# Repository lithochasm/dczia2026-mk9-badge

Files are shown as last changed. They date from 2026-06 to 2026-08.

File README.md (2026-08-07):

```
___  ____     _____  ______           _            
|  \/  | |   |  _  | | ___ \         | |           
| .  . | | __| |_| | | |_/ / __ _  __| | __ _  ___ 
| |\/| | |/ /\____ | | ___ \/ _` |/ _` |/ _` |/ _ \
| |  | |   < .___/ / | |_/ / (_| | (_| | (_| |  __/
\_|  |_/_|\_\\____/  \____/ \__,_|\__,_|\__, |\___|
                                         __/ |     
                                        |___/      
-------------------------------------------------
D C Z I A  ----------  2 0 2 6
```

DCZia Presents: The MK9 Badge

It blinks. It types. You can wear it around your neck and then set it on your desk and actually use it\*.

\* _Desk productivity not guaranteed. DCZia assumes no responsibility for keys accidentally sent during badge parties. Consult your keyboard layer documentation before operating heavy machinery._

---

## About

The **MK9** is a fully functional **3×3 mechanical macropad badge**. Nine real mechanical switches, per-key RGB lighting, ambient underglow, an accelerometer that actually does something interesting, SAO support, and MicroPython firmware — all in a package sized to hang around your neck at DEF CON and survive the week.

---

## Specs

**Keys**
- 9× mechanical switches in a 3×3 grid — standard MX footprint, swap keycaps as you please
- Ships with translucent blue keycaps
- USB HID numpad when plugged into a computer

**Lighting**
- 9× WS2812B per-key RGB LEDs — one under each switch
- 6× SK6812 side-firing LEDs — edge-mounted for ambient underglow out the sides

**Brains & Sensors**
- RP2040 microcontroller
- Accelerometer — light stays pooled at physical down as a hanging badge rotates
- 2× SAO connectors (standard 6-pin, I2C + 2 GPIO each) — expand with the badge add-on ecosystem

**Power & I/O**
- USB-C — power and data
- 3× AAA battery pack — run it untethered
- Power switch for battery mode
- Reset button + BOOTSEL button for easy firmware flashing

**Firmware**
- Native MicroPython firmware with bundled USB HID support
- QMK-compatible hardware — reflash and run it as a full QMK macropad

---

## What It Does Out of the Box

On boot: a smoothly fading rainbow flows across all keys and backlights, then
cross-fades into the active theme.

Once running:
- Nine spatial color themes animate all 15 LEDs — one theme for each key
- Pressing a key makes a white-hot impact and a colour ripple that expands across the whole board
- Long-press a key to select its theme; rotation keeps its light pooled at physical down
- Plug into a computer and it shows up as a numpad (7–9 / 4–6 / 1–3 layout)

---

## Repository

```
mk9-badge/
├── buildguide.md — badge assembly, flashing, and troubleshooting
├── hardware/   — KiCad design files, BOM, fabrication outputs
└── software/   — MicroPython firmware
```

- [Build Guide →](buildguide.md) — assembly, battery installation, flashing, and troubleshooting
- [Hardware →](hardware/README.md) — schematics, PCB layout, drill files, BOM
- [Software →](software/README.md) — firmware architecture, pinout, library requirements, flashing instructions

**Fabrication outputs**:
- [PCB layer plot](hardware/output/mk9-badge.pdf)
- [PTH drill map](hardware/output/mk9-badge-PTH-drl_map.pdf)
- [NPTH drill map](hardware/output/mk9-badge-NPTH-drl_map.pdf)

---

## Programming / Updating

The badge runs [MicroPython](https://micropython.org). To install or update it:

1. Hold **BOOTSEL** while plugging the badge into your computer — it mounts as `RPI-RP2`.
2. Drag [`firmware/RPI_PICO-20260406-v1.28.0.uf2`](firmware/RPI_PICO-20260406-v1.28.0.uf2)
   onto the drive.
3. Use Thonny or `mpremote` to upload the `software/*.py` files to `/` and
   `software/lib/` to `/lib/` on the badge.

Full commands and the recommended firmware version are in the
[software flashing guide](software/README.md#install-on-the-badge).

Want to run QMK instead? The hardware is fully compatible; QMK setup instructions will be posted separately.

**Recommended tool:** [Thonny](https://thonny.org), which can edit and upload
files directly through the MicroPython serial connection.

---

## Open Source

DCZia is committed to open source hardware and software. All design files and firmware are publicly available.

- **Live CAD (OnShape):** [View the design](https://cad.onshape.com/documents/36884624fbe35c16a5af61a7/w/233227193d278274727a44c3/e/ea987b4b53c4648fa3dc84b6)

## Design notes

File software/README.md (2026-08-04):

# MK9 Badge — MicroPython Firmware

Native MicroPython firmware for the RP2040-based DCZia MK9 badge. It has no
runtime dependency on CircuitPython or Adafruit libraries.

## Behavior

Startup is a 3.2-second smoothly fading, moving rainbow that cross-fades into
the active theme. Normal key taps still send the USB numpad layout:

```text
7 8 9
4 5 6
1 2 3
```

Hold a key for 750 ms to select its theme. A long press changes lighting and
does not send a number:

| Key | Theme |
|---:|---|
| 1 | Party Mode |
| 2 | Vaporwave |
| 3 | Deep Ocean |
| 4 | Ember |
| 5 | Matrix |
| 6 | Ultraviolet |
| 7 | Sunset |
| 8 | Glacier |
| 9 | Moonlight |

**Party Mode** (key 1) is a random-looking flicker across all 15 LEDs,
pulsing at 175 BPM by default: each beat snaps to a new random pattern,
holds it for the first 55% of the beat, then blacks out for the rest before
the next beat's pattern snaps in. The tempo is adjustable live with the
`bpm` command (see below), or
directly from the badge: while Party Mode is active, key 7 nudges it down
and key 8 nudges it up, 2 BPM per short press, and key 9 is a tap-tempo
input — tap it in time with music and the average interval between taps
becomes the new BPM (a gap longer than 2 seconds since the last tap starts a
fresh tapping sequence instead of averaging with stale ones). While Party
Mode is active, physical key presses otherwise stop sending USB numpad
keystrokes (long-press theme selection still works on every key, including
7, 8, and 9, so you can always long-press back out into a different theme).

There's also a 10th theme, **Prism** — the original default rainbow — which
isn't bound to a key (there are only 9 for 10 themes), so reach it from the
serial console with `theme 10` or `theme prism`.

Every press creates a spatial ripple. As a hanging badge rotates, the current
theme's light quickly follows physical down and gathers like liquid at the
lowest edge or corner, with a short overshoot and settling shoreline wobble.
Forward/back tilt and quick movement do not change the pool while it is
hanging; Z smoothly suppresses the effect when the badge is laid flat. If the
accelerometer is not responding, the keys, LEDs, and USB keyboard continue to
work.

## Hardware map

| Function | GPIO |
|---|---|
| 15-pixel WS2812/SK6812 chain | GP21 |
| Matrix rows R0/R1/R2 | GP27, GP26, GP16 |
| Matrix columns C0/C1/C2 | GP17, GP13, GP0 |
| MSA301/GSDA213 SDA/SCL | GP18, GP19 (I2C1) |
| SAO SDA/SCL | GP9, GP10 (software I2C) |
| SAO GPIO | GP29, GP28, GP12, GP11 |

The key scanner drives one column high and reads rows with pull-downs. This
matches the PCB's column → switch → diode → row orientation.

### Physical layout

Traced from the PCB netlist (switch → diode → row nets, and each LED's
DIN/DOUT chain position), viewed from the front of the badge:

```text
                 ┌──[pwr]──[ USB-C ]──[boot]──[reset]──┐
                 │                                     │
     D27 ●       │    [ 7 ]      [ 8 ]      [ 9 ]      │       ● D22
  (pixel 14)     │   key 0       key 1       key 2     │    (pixel 9)
                 │   pixel 0     pixel 1     pixel 2   │
                 │                                     │
                 │    [ 4 ]      [ 5 ]      [ 6 ]      │
                 │   key 3       key 4       key 5     │
     D26 ●       │   pixel 3     pixel 4     pixel 5   │       ● D23
  (pixel 13)     │                                     │    (pixel 10)
                 │    [ 1 ]      [ 2 ]      [ 3 ]      │
                 │   key 6       key 7       key 8     │
                 │   pixel 6     pixel 7     pixel 8   │
                 │                                     │
                 └──────────●───────────●──────────────┘
                           D25          D24
                        (pixel 12)   (pixel 11)
```

| Key index | Pixel index | Numpad digit | Row/Col nets | Switch ref | LED ref | Physical position |
|---|---|---|---|---|---|---|
| 0 | 0 | 7 | R0,C0 | SW4 | D13 | top-left |
| 1 | 1 | 8 | R0,C1 | SW5 | D14 | top-middle |
| 2 | 2 | 9 | R0,C2 | SW6 | D15 | top-right |
| 3 | 3 | 4 | R1,C0 | SW7 | D16 | mid-left |
| 4 | 4 | 5 | R1,C1 | SW8 | D17 | mid-middle |
| 5 | 5 | 6 | R1,C2 | SW9 | D18 | mid-right |
| 6 | 6 | 1 | R2,C0 | SW10 | D19 | bottom-left |
| 7 | 7 | 2 | R2,C1 | SW11 | D20 | bottom-middle |
| 8 | 8 | 3 | R2,C2 | SW12 | D21 | bottom-right |

Key index and pixel index match for all 9 keys — the per-key LEDs are simply
the first 9 pixels in the chain, so `badge.py` indexes straight into
`frame[key]` with no translation. Pixels 9-14 are the 6 side-firing
underglow LEDs (2 per left/right edge, 2 along the bottom); the top edge has
none since it's occupied by USB-C, the power switch, and the reset/BOOTSEL
buttons.

## Firmware structure

```text
software/
├── boot.py          USB serial + HID setup
├── main.py          MicroPython entry point
├── badge.py         keys, long presses, motion, ripples, main loop
├── themes.py        startup rainbow and all nine themes
├── hardware.py      NeoPixels, matrix, accelerometer, and SAO setup
├── key_matrix.py    active-high scanner with software debounce
├── msa301.py        native accelerometer driver
├── color_tools.py   portable RGB math
├── config.py        pins and user-tunable timing/brightness
├── usb_keyboard.py  non-blocking numpad reports
├── serial_menu.py   typed USB-serial console (help/status/theme/brightness/accel/reset/bootloader)
├── rooms.py         text-adventure room data — this is where you write your game
├── game.py          text-adventure state machine (movement, inventory, save/load)
├── user_config.py   persisted theme/brightness/party-bpm settings, loaded on boot
└── lib/usb/         official MicroPython USB device libraries
```

## Serial console

While the badge is running (not just at the REPL), the USB-CDC serial
connection also accepts typed commands — connect with `mpremote connect auto
repl`, Thonny's shell, or any serial terminal, then type `help` and press
Enter for the full command listing (`status`, `theme [n|name]`, `brightness
[0-100]`, `bpm [1-999]`, `accel`, `reset`, `bootloader`). Typing anything at
all before you've seen the listing prints it automatically. Ctrl-C still
drops to the real MicroPython REPL and kills the running badge script, same
as always — that's unrelated to and unaffected by the console.

Changing the theme (long-press or `theme`), `brightness`, or `bpm` (Party
Mode's tempo) saves all three settings to `/user_config.json` on the badge's
flash filesystem, and they're restored automatically the next time the badge
boots.

## Text adventure

Typing `play` at the serial console starts a small text-adventure game that
runs inside the same firmware, taking over the typed console until you type
`quit`. All game content — room names/descriptions, exits, and puzzles —
lives in `rooms.py`; fill that in with your own 9 rooms. `game.py`'s
plumbing (movement, inventory, save/load, room-status LEDs) needs no changes
to add content.

While the game is active the 9 physical keys stop sending USB numpad
keystrokes and stop selecting lighting themes. Instead, each key becomes a
purely visual status board for the room of the same index (key 1 = room 0,
etc.) — pressing a key does not move you:

| Color  | Meaning |
|---|---|
| Red | Room not yet visited |
| Yellow | Visited, puzzle not yet solved  |
| Green  | Visited, puzzle solved |

Commands: `look`, `go <direction>` (per-room exits, not fixed compass
directions), `take` (picks up the current room's item, if any), `use <item>`
(only works on items you're carrying), `hint`, `inventory` (`inv`/`i`),
`save`, `load`, `restart` (wipes progress and starts over), `help`, `quit`.
Progress saves to `/game_save.json` on the badge's flash filesystem
automatically when you `quit`, or on demand with `save`.

## Install on the badge

1. Hold **BOOTSEL** while plugging in the badge. It appears as `RPI-RP2`.
2. Copy the included `firmware/RPI_PICO-20260406-v1.28.0.uf2` onto `RPI-RP2`.
   It is the official stable v1.28 build from
   [micropython.org/download/RPI_PICO](https://micropython.org/download/RPI_PICO/).
3. The badge reboots into MicroPython. Unlike CircuitPython, it does not expose
   a drag-and-drop source drive. Use Thonny or `mpremote` to upload the files.

In Thonny, select **MicroPython (Raspberry Pi Pico)**, then upload every `.py`
file in `software/` to `/` and upload `software/lib/` as `/lib/`.

With `mpremote`:

```sh
cd software
mpremote connect auto fs mkdir :lib
mpremote connect auto fs mkdir :lib/usb
mpremote connect auto fs mkdir :lib/usb/device
mpremote connect auto fs cp *.py :
mpremote connect auto fs cp lib/usb/__init__.py :lib/usb/__init__.py
mpremote connect auto fs cp lib/usb/device/*.py :lib/usb/device/
mpremote connect auto reset
```

From the repository root, `tools/upload_micropython.sh` runs those commands
for you.

If a directory already exists, its `mkdir` command may print an error; continue
with the copy commands. `boot.py` deliberately keeps the serial REPL enabled
while adding the HID keyboard.

## Configuration

Edit `config.py` to change global brightness, long-press time, frame rate, or
pin assignments. Add or modify palettes and renderers in `themes.py`.
`GLOBAL_BRIGHTNESS` and `PARTY_BPM` are only the boot-time defaults — the
serial console's `brightness` and `bpm` commands can also change them live,
without reflashing, and those choices (along with the active theme) persist
across reboots via `user_config.py`.

## Verification

Host-side logic tests do not require a badge:

```sh
python3 -m unittest discover -s tests -v
python3 -m compileall -q software testing tests
```

For physical diagnostics, see [`testing/README.md`](../testing/README.md).

The bundled `lib/usb/` modules come from the official MIT-licensed
`micropython-lib` project; its license is retained under `third_party/`.

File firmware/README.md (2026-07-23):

# MicroPython UF2

`RPI_PICO-20260406-v1.28.0.uf2` is the official stable MicroPython v1.28.0
firmware for the Raspberry Pi Pico/RP2040 target, downloaded from:

<https://micropython.org/download/RPI_PICO/>

SHA-256:

```text
00aedb8431ebea83b470ef909509f16432c5b1b43e8f6eaf015f6f9560bc8152
```

Hold BOOTSEL while plugging in the badge, then copy the UF2 onto the `RPI-RP2`
drive. The drive will disappear when flashing finishes. Upload the Python files
afterward using Thonny or `tools/upload_micropython.sh`.

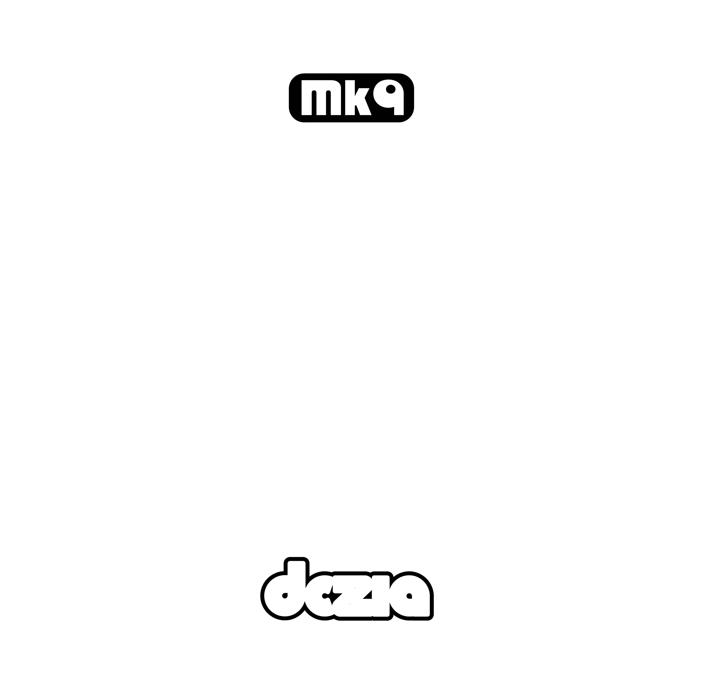
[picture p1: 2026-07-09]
hardware/images/Board_Silk.png

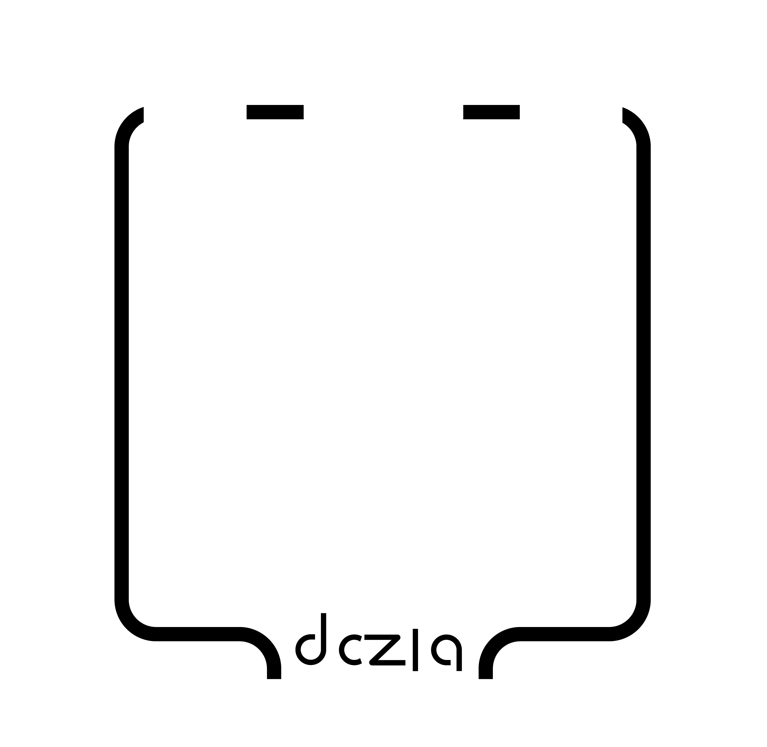
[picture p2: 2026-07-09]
hardware/images/Board_Copper.png

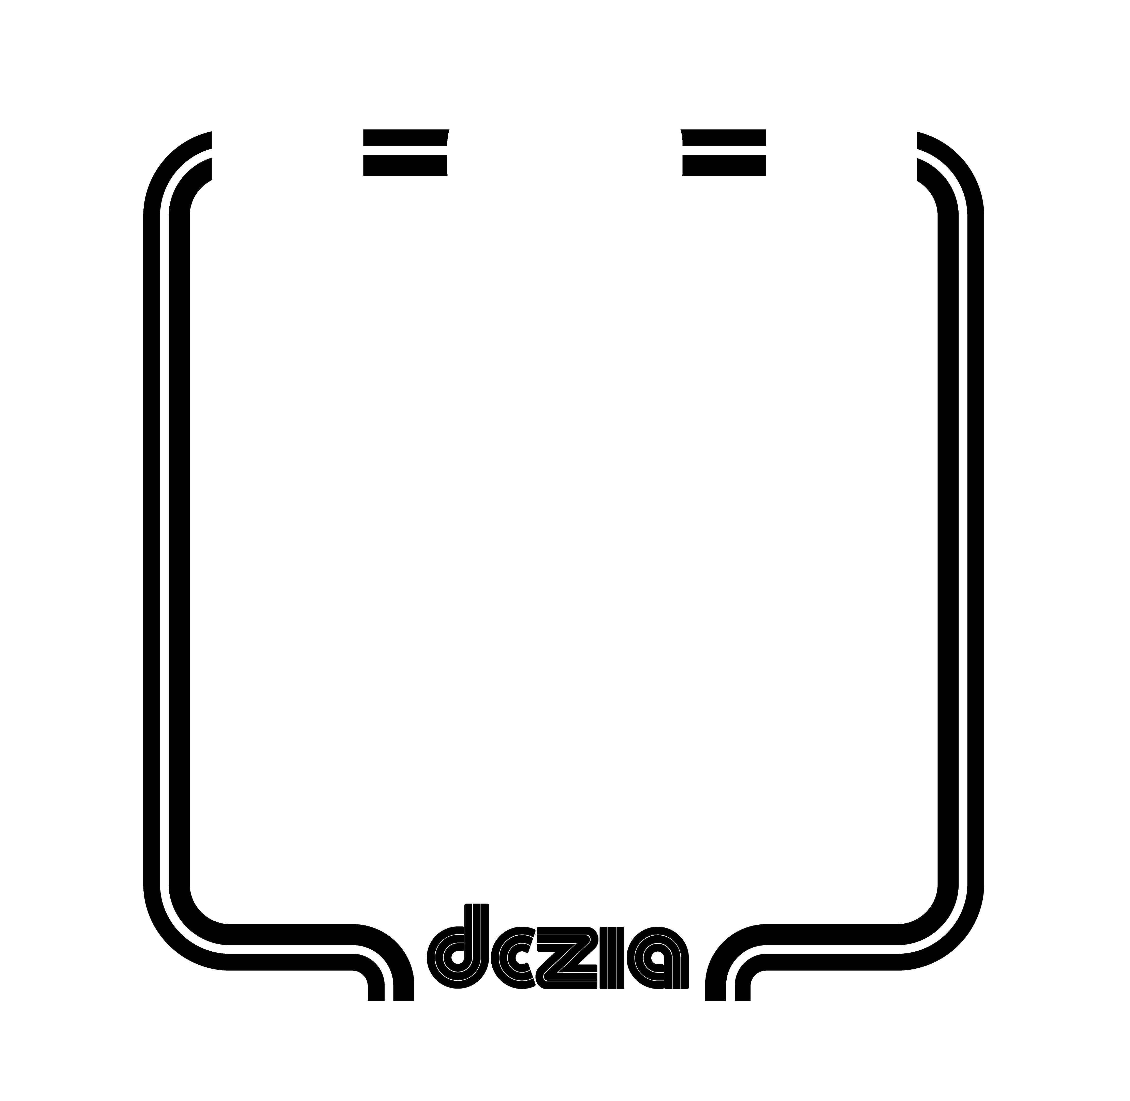
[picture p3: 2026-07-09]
hardware/images/Board_Mask.png

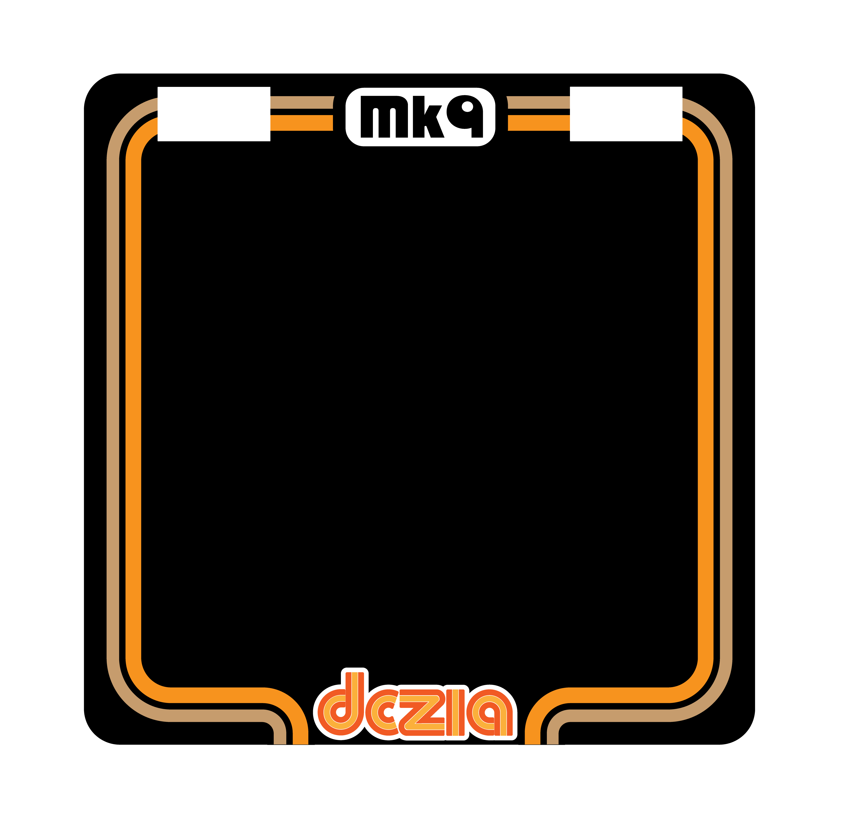
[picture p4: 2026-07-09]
hardware/images/Board_Art.png

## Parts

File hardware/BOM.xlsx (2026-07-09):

Reference | Feeder | Value | Footprint | Part Number | Distributor | Distributor Part | Datasheet | Qty | Cost Each | Qty Ordered | QOH | Notes
C3,C5,C6,C8-C12,C15-C20 |  | 0.1uF | 0603 |  |  |  | ~ | 14 | 0.004 | 0 | 2500
C4,C7,C13,C14 |  | 1uF | 0603 |  |  |  | ~ | 4 | 0.004 | 0 | 3500
C1,C2 |  | 15pF | 0603 |  |  |  | ~ | 2 | 0.004 | 0 | 3500
D2-12 |  | D_Schottky | SOD-123 |  | Digikey | 3757-SS0540_R1_00001DKR-ND | https://www.panjit.com.tw/upload/datasheet/SS0520_SERIES.pdf | 2 | 0.11 | 0 | 2500
D13-21 |  | WS2812B | LED_SMD:LED_WS2812B_PLCC4_5.0x5.0mm_P3.2mm |  | Aliexpress | https://www.aliexpress.us/item/2251832628463811.html | https://cdn-shop.adafruit.com/datasheets/WS2812B.pdf | 9 | 0.07 | 0 | 2000
D22-27 |  | SK6812 |  |  | Aliexpress |  |  | 6 | 0.1 | 1000 | 0
D1 |  | TVS |  | SP0502BAHTG | Mouser | 576-SP0502BAHTG | https://www.littelfuse.com/assetdocs/tvs-diode-array-spasp050xba-lead-free-green-datasheet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 | 0 | 0.383 |  |  | Optional stuffing
J1 |  | USB-C | Connector_USB:USB_C_Receptacle_HCTL_HC-TYPE-C-16P-01A |  | Aliexpress | https://www.aliexpress.us/item/3256805324706422.html | https://www.lcsc.com/datasheet/lcsc_datasheet_2211161000_HCTL-HC-TYPE-C-16P-01A_C2894897.pdf | 1 | 0.19 | 150 | 100
R1,R7 |  | 1k | 0603 |  |  |  | ~ | 2 | 0.001 | 0 | 4500
R6,R8 |  | 10k | 0603 |  |  |  | ~ | 2 | 0.001 | 0 | 4500
R2,R3 |  | 5.1k | 0603 |  |  |  | ~ | 2 | 0.001 | 0 | 4500
R4,R5 |  | 27R | 0603 |  |  |  | ~ | 2 | 0.001 | 0 | 4500
R9 |  | 10R | 0603 |  |  |  | ~ | 1 | 0.001 | 0 | 4500
R10,R11 |  | 4.7k | 0603 |  |  |  |  | 2 | 0.001 | 5000 | 0
S1,S3 |  | SPST Push w/boss | Button_Switch_SMD:SW_SPST_EVQP7C | EVQ-P7C01P | Digikey | P16765CT-ND | https://api.pim.na.industrial.panasonic.com/file_stream/main/fileversion/245500 | 2 | 0.20204 | 300 | 0
S2 |  | SW_SPDT | lib_fp:SW_SPDT_CK-JS102011SAQN | JS102011SAQN | Digikey | 401-1999-1-ND | https://ckswitches.com/media/1422/js.pdf | 1 | 0.6032 | 150 | 0
S4-12 |  | CherryMX Blue |  |  | Aliexpress |  |  | 9 | 0.1 | 1000 | 0
U3 |  | NCP115ASN330T2G | Package_TO_SOT_SMD:SOT-23-5 | NCP115ASN330T2G | Digikey | NCP115ASN330T2G | https://www.onsemi.com/pdf/datasheet/ncp115-d.pdf | 1 | 0.0677 | 0 | 2500
U2 |  | RP2040 | Package_DFN_QFN:QFN-56-1EP_7x7mm_P0.4mm_EP3.2x3.2mm | SC0914(7) | Mouser | 358-SC09147 | https://datasheets.raspberrypi.com/rp2040/rp2040-datasheet.pdf | 1 | 0.8 | 0 | 1000
U4 |  | W25Q128JVSIM |  |  | Digikey | W25Q128JVSIM-ND | https://www.winbond.com/resource-files/W25Q128JV%20RevI%2008232021%20Plus.pdf | 1 | 2.51556 | 133 | 0
U1 |  | GSDA213 | Kionix_LGA-12_2x2mm_P0.5mm_LayoutBorder2x4y | GSDA213 | Digikey | 4786-GSDA213TR-ND | https://goodarksemi.com/docs/datasheets/mems/GSDA213_SDS.pdf | 1 | 0.6595 | 150 | 0
X1,X2 |  | Badgelife_sao_connector_v169bis | lib_fp:Badgelife-Shitty-v1.69bis | VIRTUAL |  |  |  | 2
Y1 |  | Crystal | Crystal:Crystal_SMD_3225-4Pin_3.2x2.5mm | ABM8-272-T3 | Digikey | 535-ABM8-272-T3DKR-ND | https://abracon.com/datasheets/ABM8-272-T3.pdf | 1 | 0.4085 | 150 | 0
 |  | Key caps |  |  |  |  |  | 9 | 0.19 | 1500
` |  | Battery boxes |  |  |  |  |  | 1 |  | 125
 |  | PCB |  |  |  |  |  | 1 |  | 200
 |  | Batteries |  |  | Amazon |  |  | 3 | 0.15 | 300
 |  | Badge Run, units | 120

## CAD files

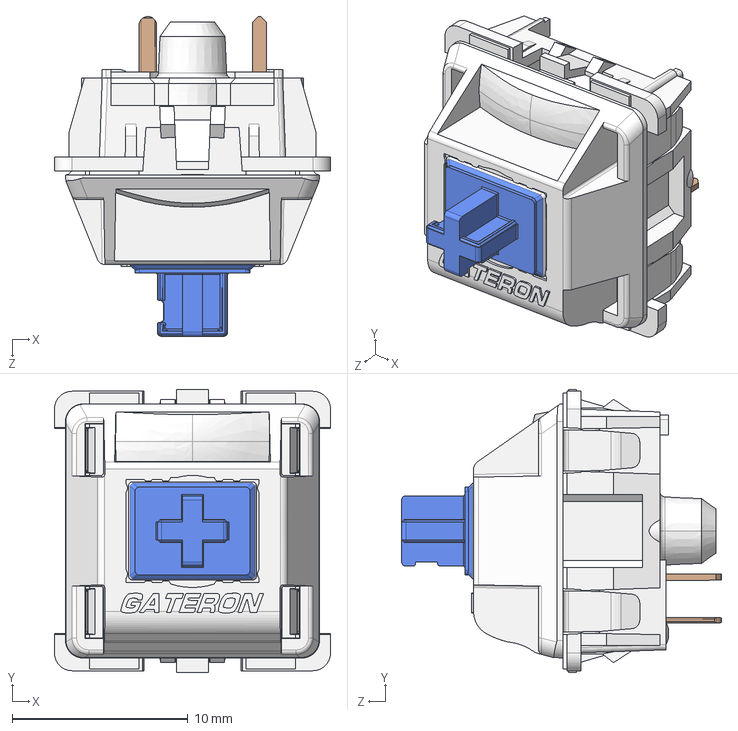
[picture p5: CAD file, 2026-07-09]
hardware/3d/G_PRO_3.0_Switch_KS-9E10B055NN-Y51_1.STEP
15.7 x 16.1 x 18.2 mm

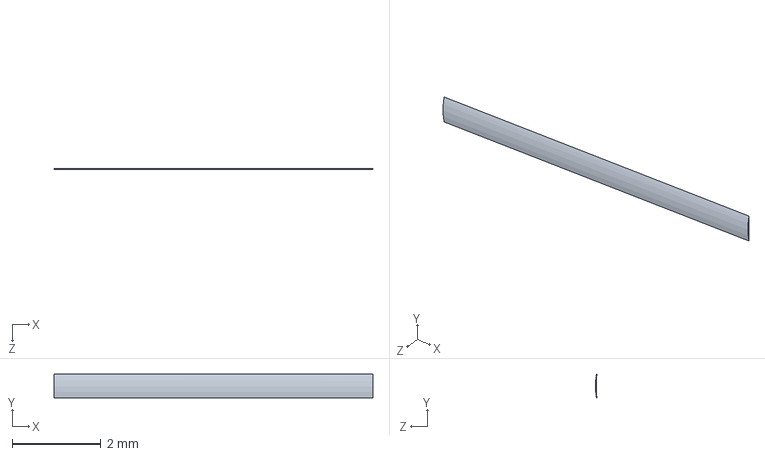
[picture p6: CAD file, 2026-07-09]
hardware/3d/G_PRO_3.0_Switch_KS-9E10B055NN-Y51_2.STEP
7.20 x 0.536 x 0.0331 mm

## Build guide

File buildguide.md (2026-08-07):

## TL;DR Instructions

1. Take the diffuser and back case off the badge using the included allen wrench
2. Solder on the keyswitches
3. Solder on the battery holder.
4. Reasseble the diffuser + case
5. Flash the badge with the u2f firmware from github / link can be found on www.dczia.net

## Intro

Thanks for purchasing the 2026 DCZia “mk9” badge! This badge is a throwback to our earlier keygrid badge from 2018. The badge features 9 mechanical MX style key switches (Gateron Blues), an accelerometer for sensing movement and adjusting the light patterns, and the badge can function as a usb keyboard / macro pad. By default the badge will output the keystrokes 1-9 like a num pad, but you can modify the code or flash QMK to use a full programmable macropad if you want. The badge is powered by an RPI 2040 microcontroller, with a 16mb flash module for expansion. An accelerometer is included as well.

## Building

The badge is shipped with the frosted diffuser, and back case pre installed. You will need to remove these pieces to safely solder on the keyswitches. Use the included allan key to disassemble the case.

[]()

Now you can install one keyswitch, and solder it onto the board. Please go slow, and try to line up the switch carefully. Sometimes some tape can be useful to keep the switch in place. Solder on all 9 key switches.

Next solder on the battery pack. The red wire will go to the “+” pad on the back of the pcb, and the black wire to the “-” pad. The badge can be fully powered over USB C if you do not wish to attach the battery pack.

After the battery pack is installed, reassemble the case, and gently screw it back together. 

Next, using the round double sticky tape, apply it to the battery pack, and then stick it to the frosted diffuser. Press gently on the battery pack for about 15 seconds to make sure you have good adhesion.

Finally install the batteries. Goto www.dczia.net, and click on the badge to be taken to the Github page for this project. Download the release which will have the source code, and a u2f file. Plug the badge into your computer and hold down the “Boot” button on the badge while plugging it in. You will need a pen or toothpick to press in the switch while plugging in the USB C cable. This will place the badge into bootloader mode. A usb drive should appear on your machine if you are using something common (Win / Mac) or if you don’t have an automounter and you are running linux, you can probably figure out how to mount the device as a drive. Drag the U2F file over to this drive. It will disconnected as soon as the transfer completes and the badge should reboot and begin showing some blinky lights!

## Badge Manual

Pressing any of the 9 keys will flash that keyswitch momentarily. Long pressing on one of the 9 keys will change the light themes. The accelerometer will allow you to tilt the badge in any of the light themes to affect the light pattern. Pressing any of the keys while plugged into usb c will output the keystroke 1-9. 

## Troubleshooting

*When i tilt my badge nothing happens?*

Some of the accelerometers may have gotten placed a bit off the pads. Find hamster for help, or if you have a hot air station, mask around the U1? part with kapton tape, and heat it gently while holding it down with some tweezers to realign to the pads. 

*Not all the keys are working?*

Re-check your solder connections on each switch

*The badge caught fire!*

The badge should only be powered by 3x AA batteries or USB-C. Please do not use car batteries, 120V AC, or small nuclear reactors to power the badge.

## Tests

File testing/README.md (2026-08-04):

# MicroPython Hardware Tester

Upload the production `software/` files first, then upload `testing/main.py`
as `/main.py` on the badge. Reset it to start the test.

- All 15 LEDs continuously sweep through red, green, and blue.
- Holding a key turns its matching LED white.
- Tilting the badge turns the matching perimeter edge white and prints live
  X/Y/Z acceleration every half second.
- If the accelerometer is missing, all six perimeter LEDs blink red.

The key numbers are row-major:

```text
1 2 3
4 5 6
7 8 9
```

Restore `software/main.py` as `/main.py` when testing is finished.

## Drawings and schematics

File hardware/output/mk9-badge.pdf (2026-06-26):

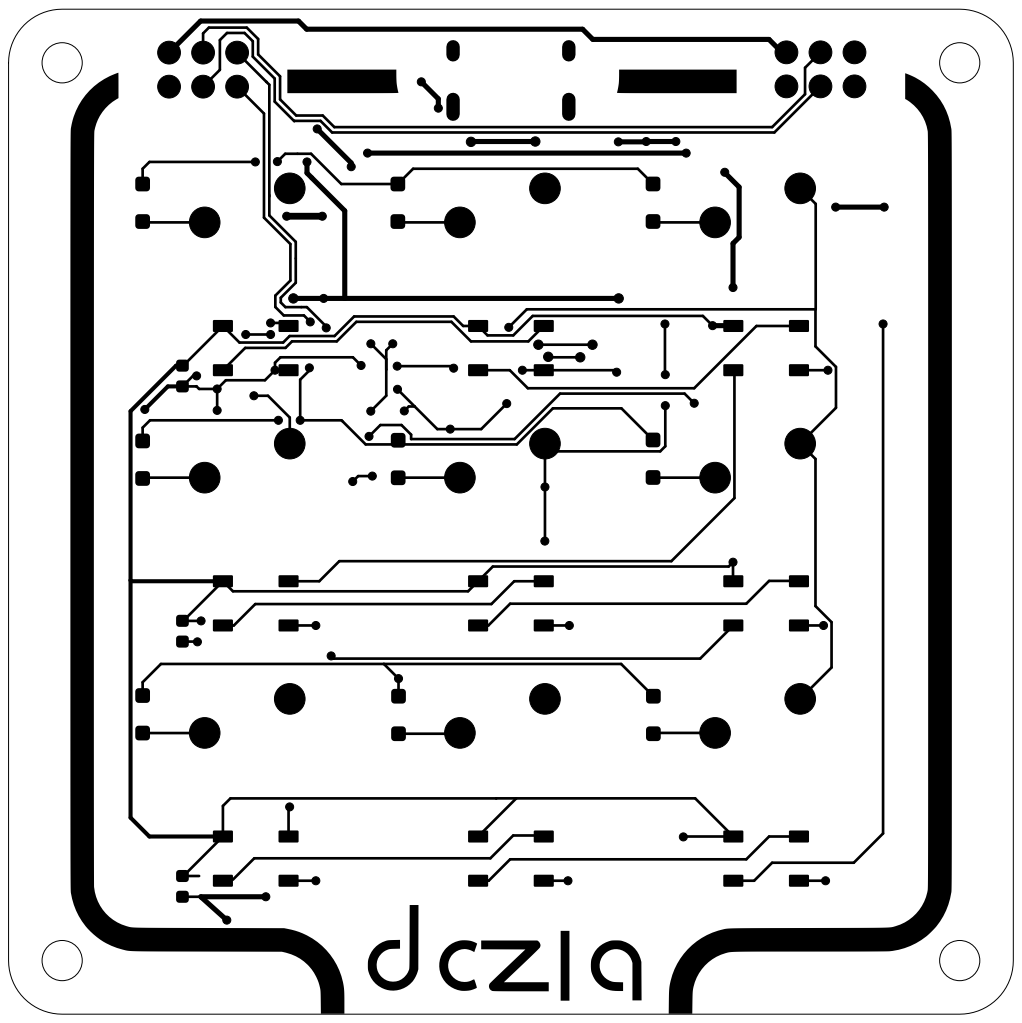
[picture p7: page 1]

Size: USLetter | Rev: 1.0
KiCad E.D.A. 10.0.4 | Id: 1/11

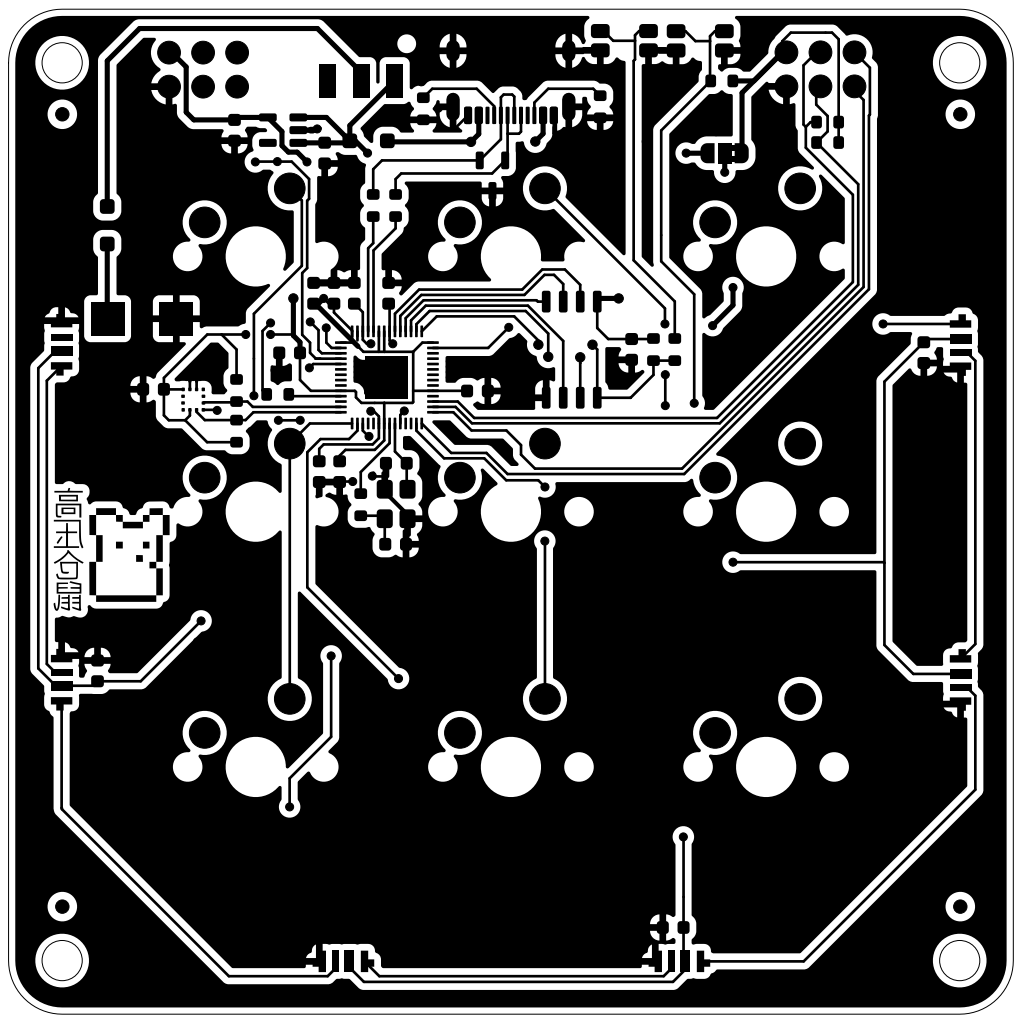
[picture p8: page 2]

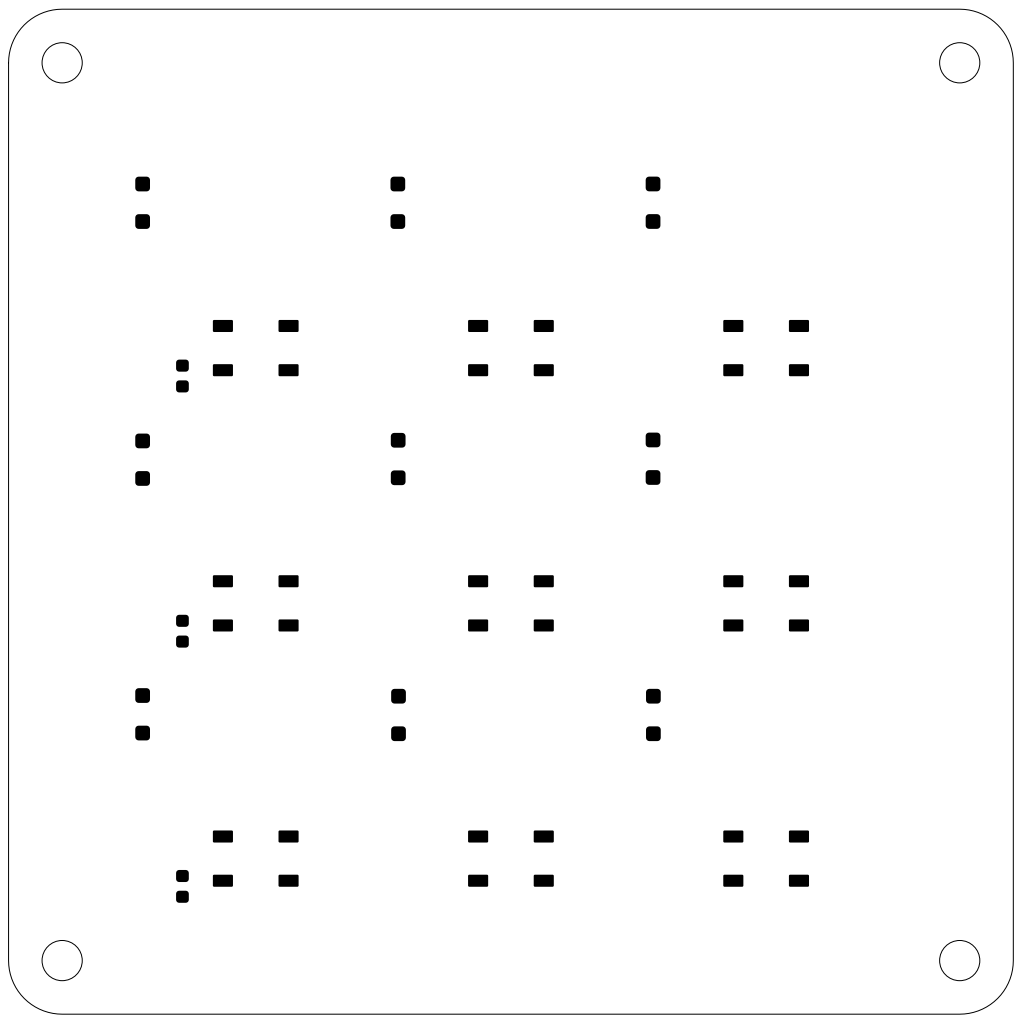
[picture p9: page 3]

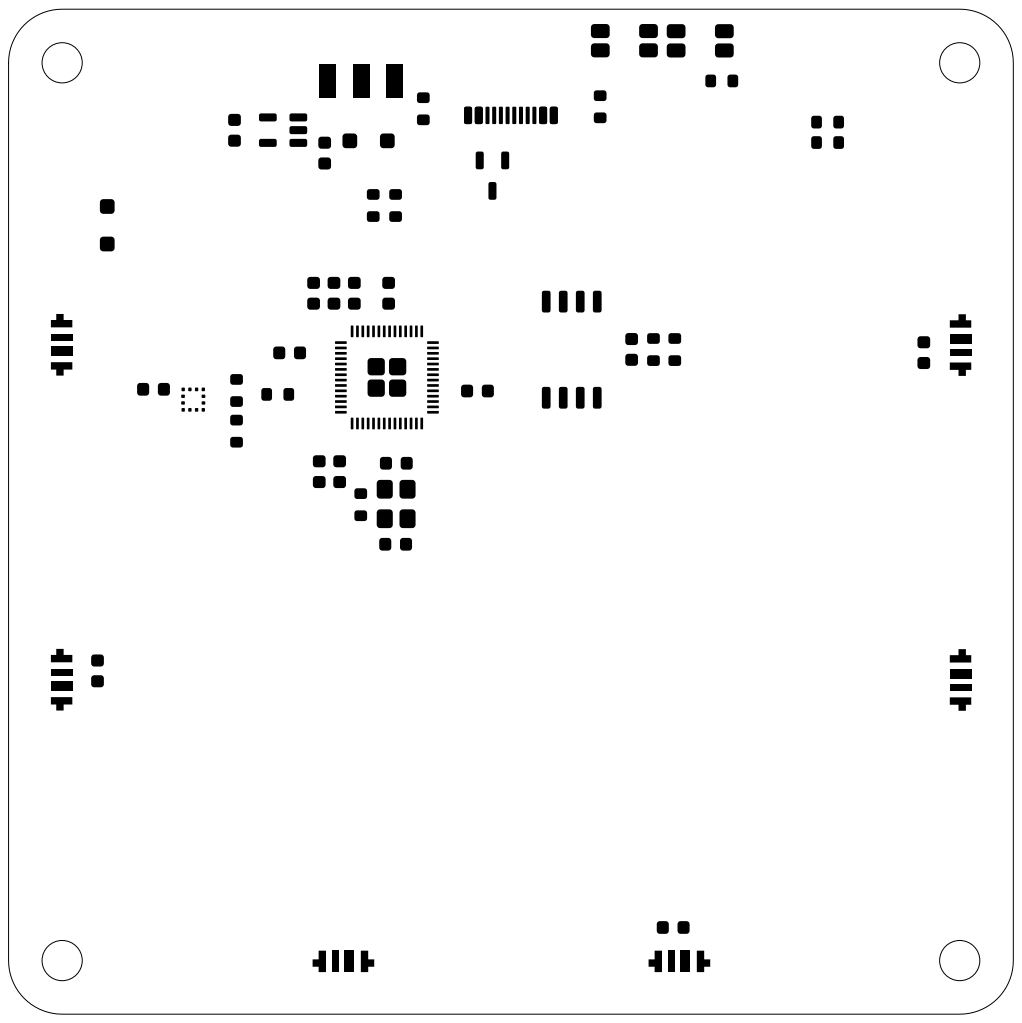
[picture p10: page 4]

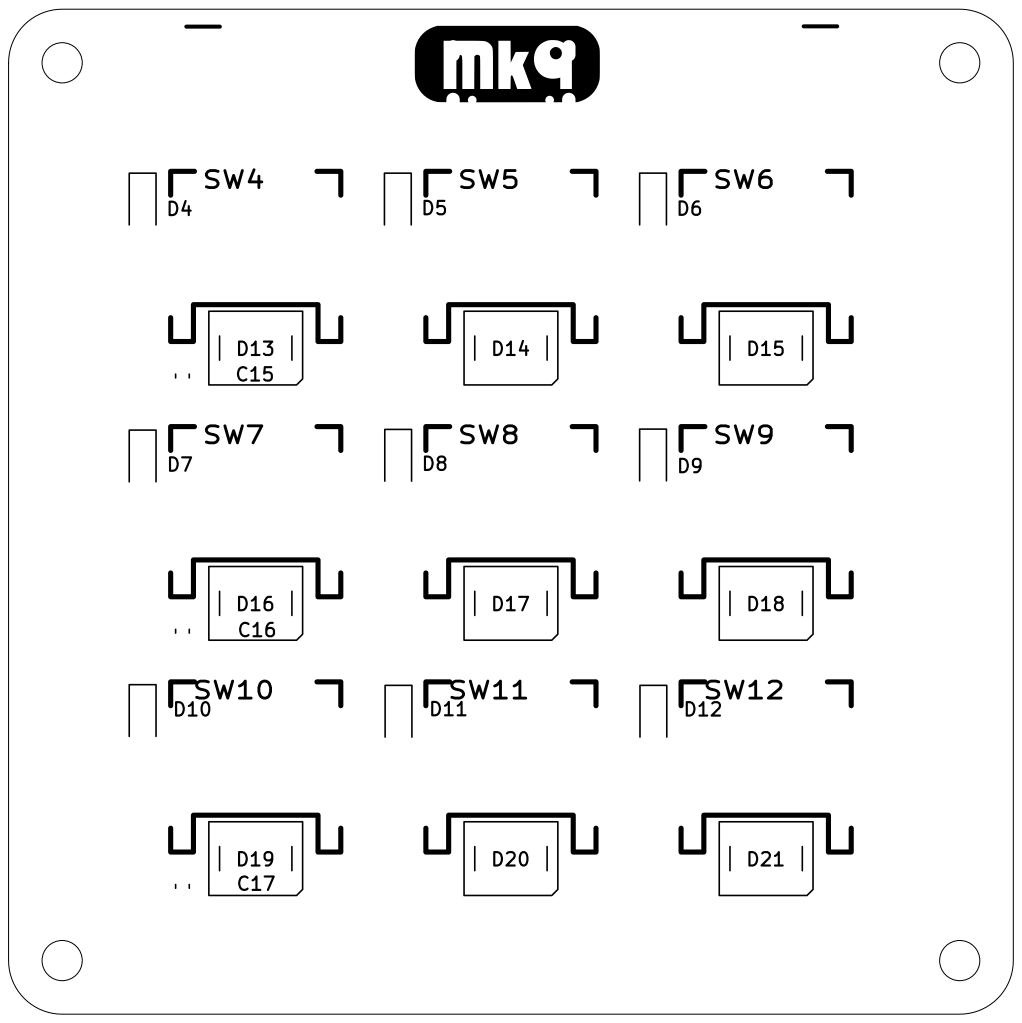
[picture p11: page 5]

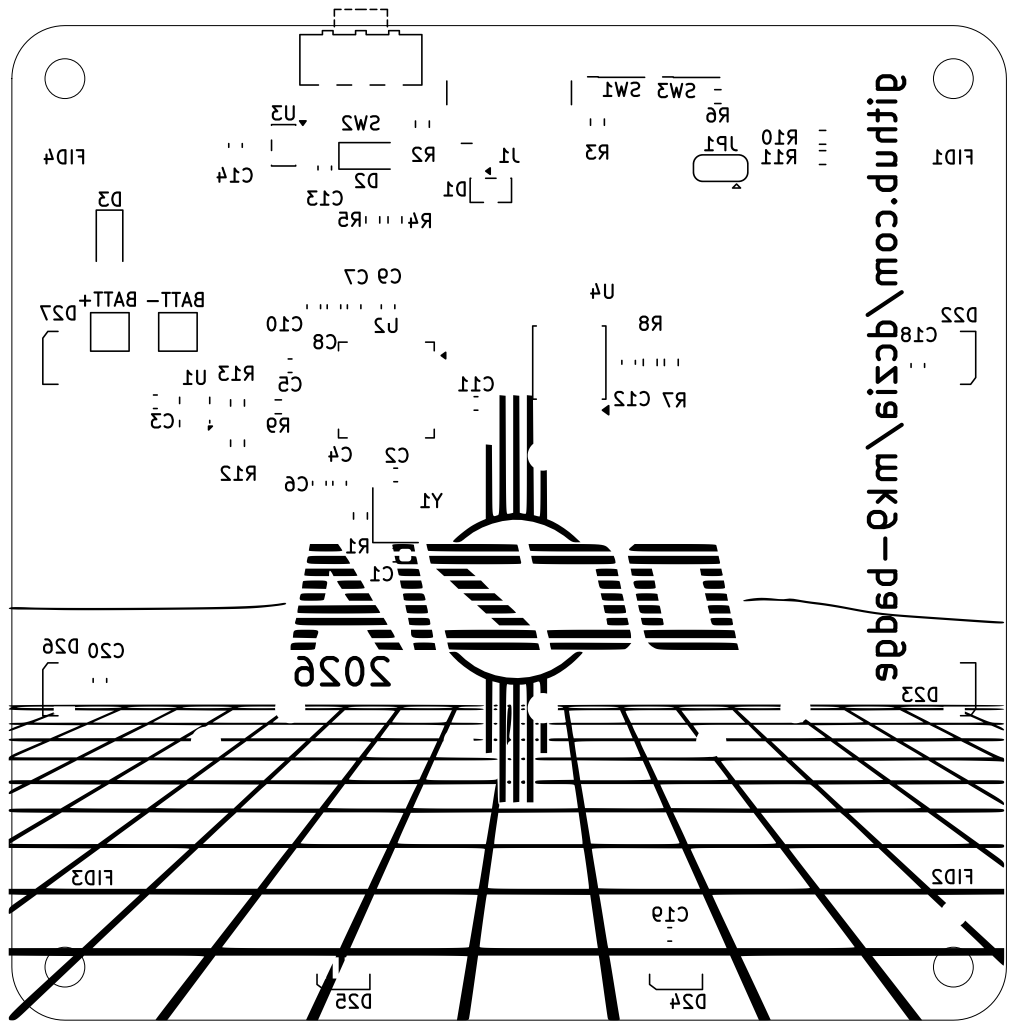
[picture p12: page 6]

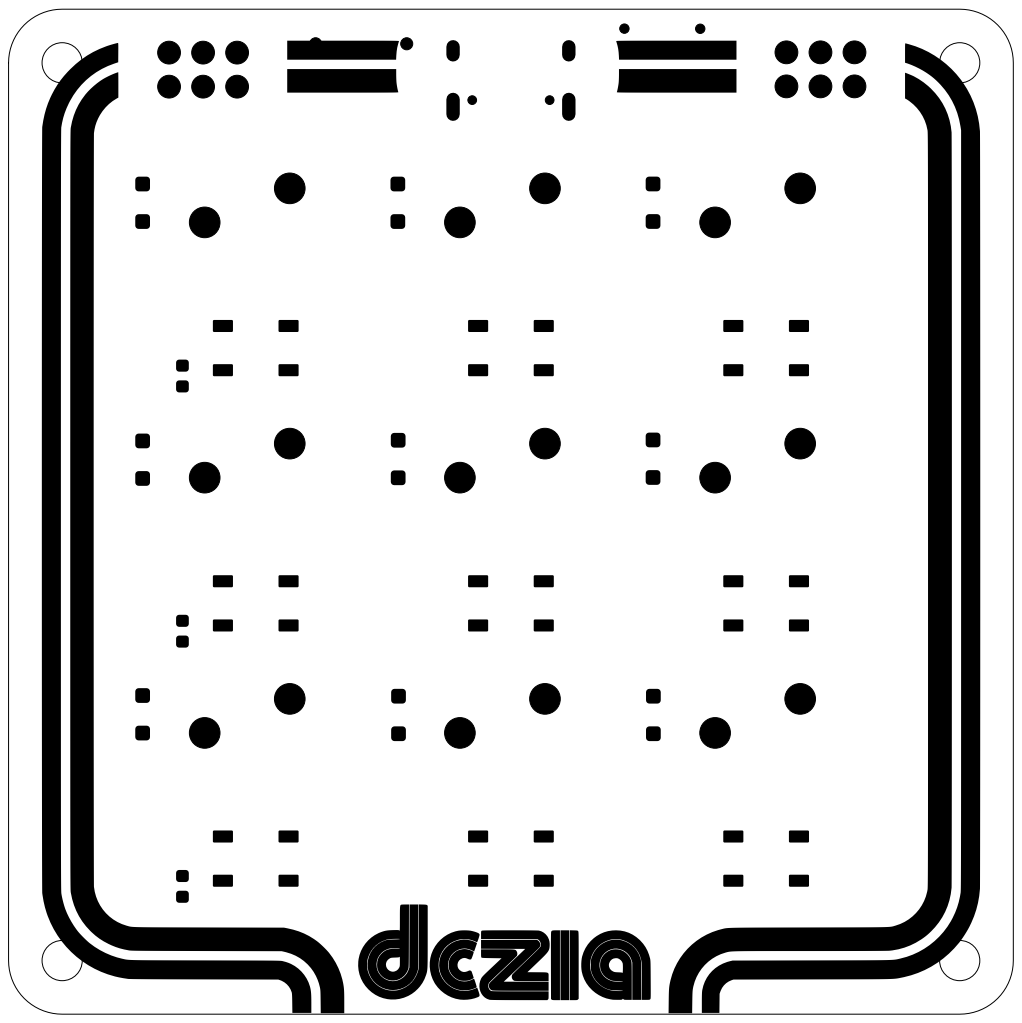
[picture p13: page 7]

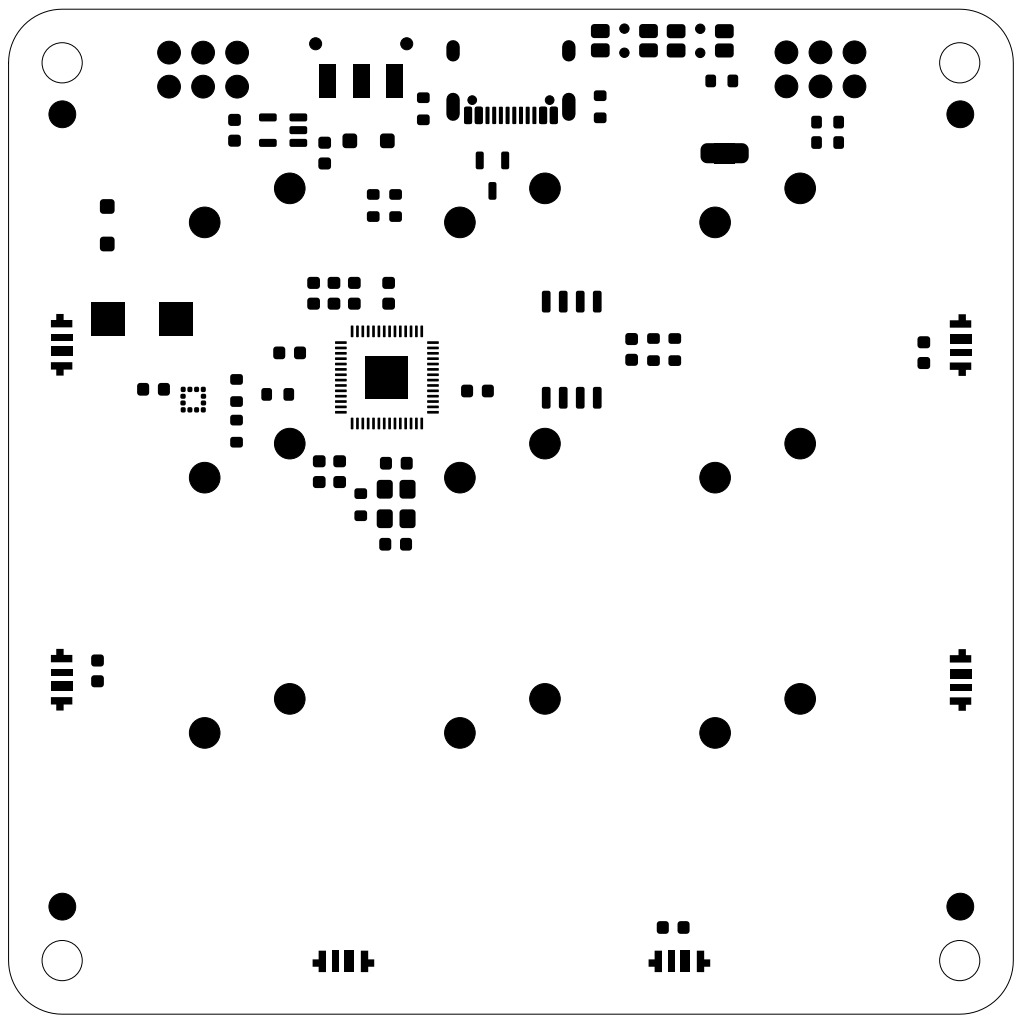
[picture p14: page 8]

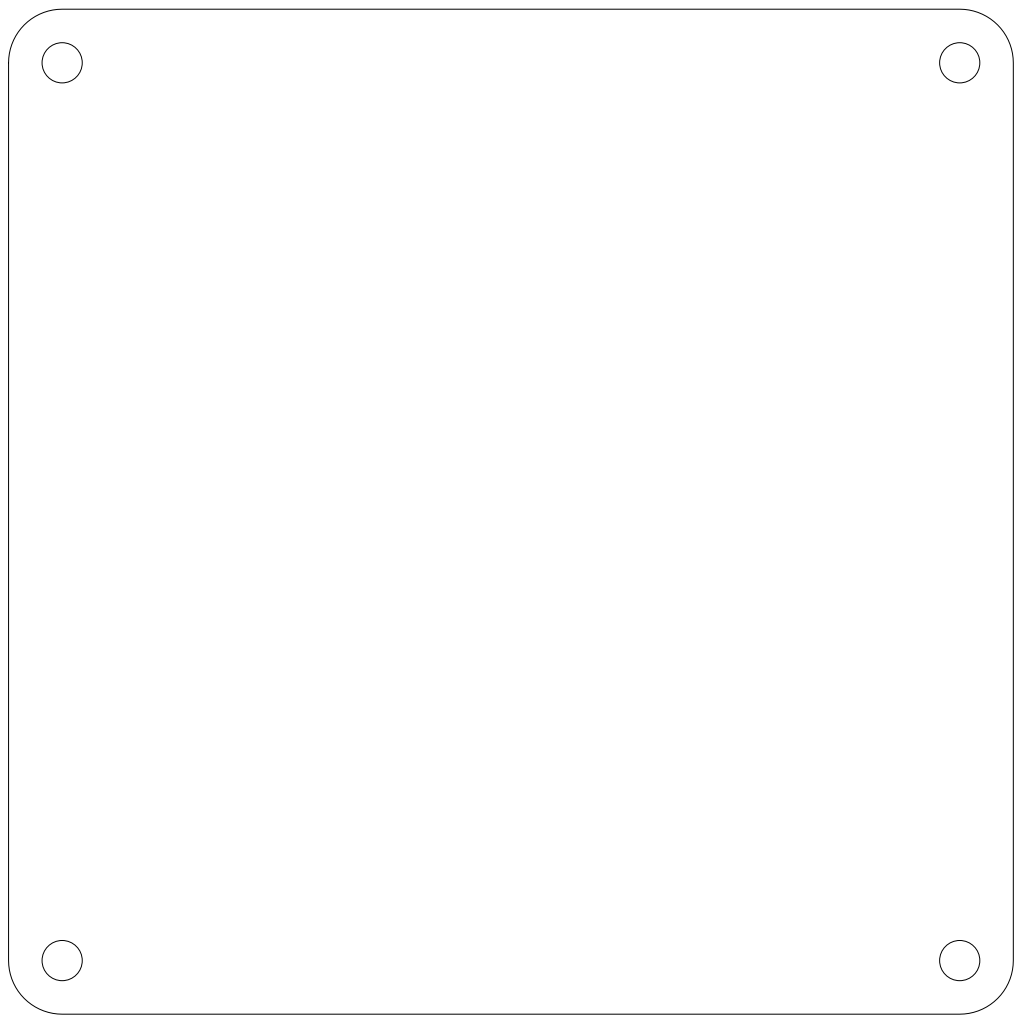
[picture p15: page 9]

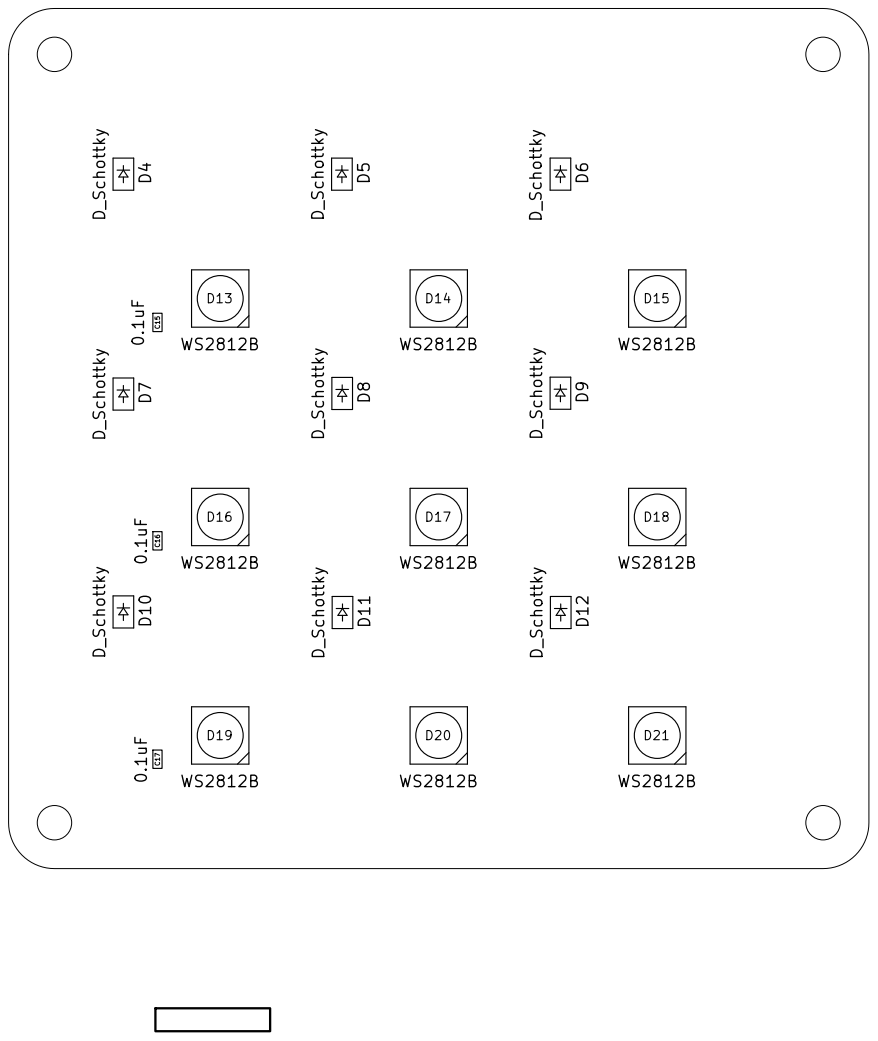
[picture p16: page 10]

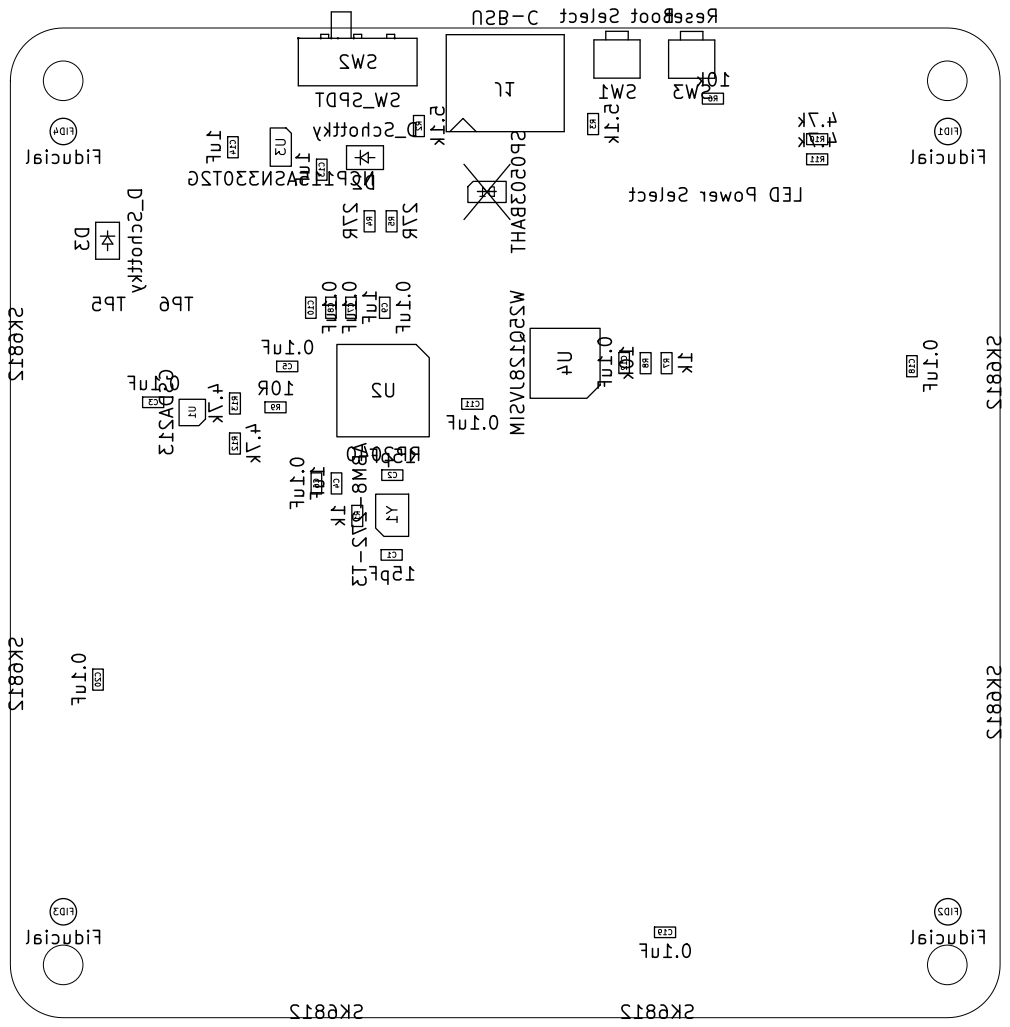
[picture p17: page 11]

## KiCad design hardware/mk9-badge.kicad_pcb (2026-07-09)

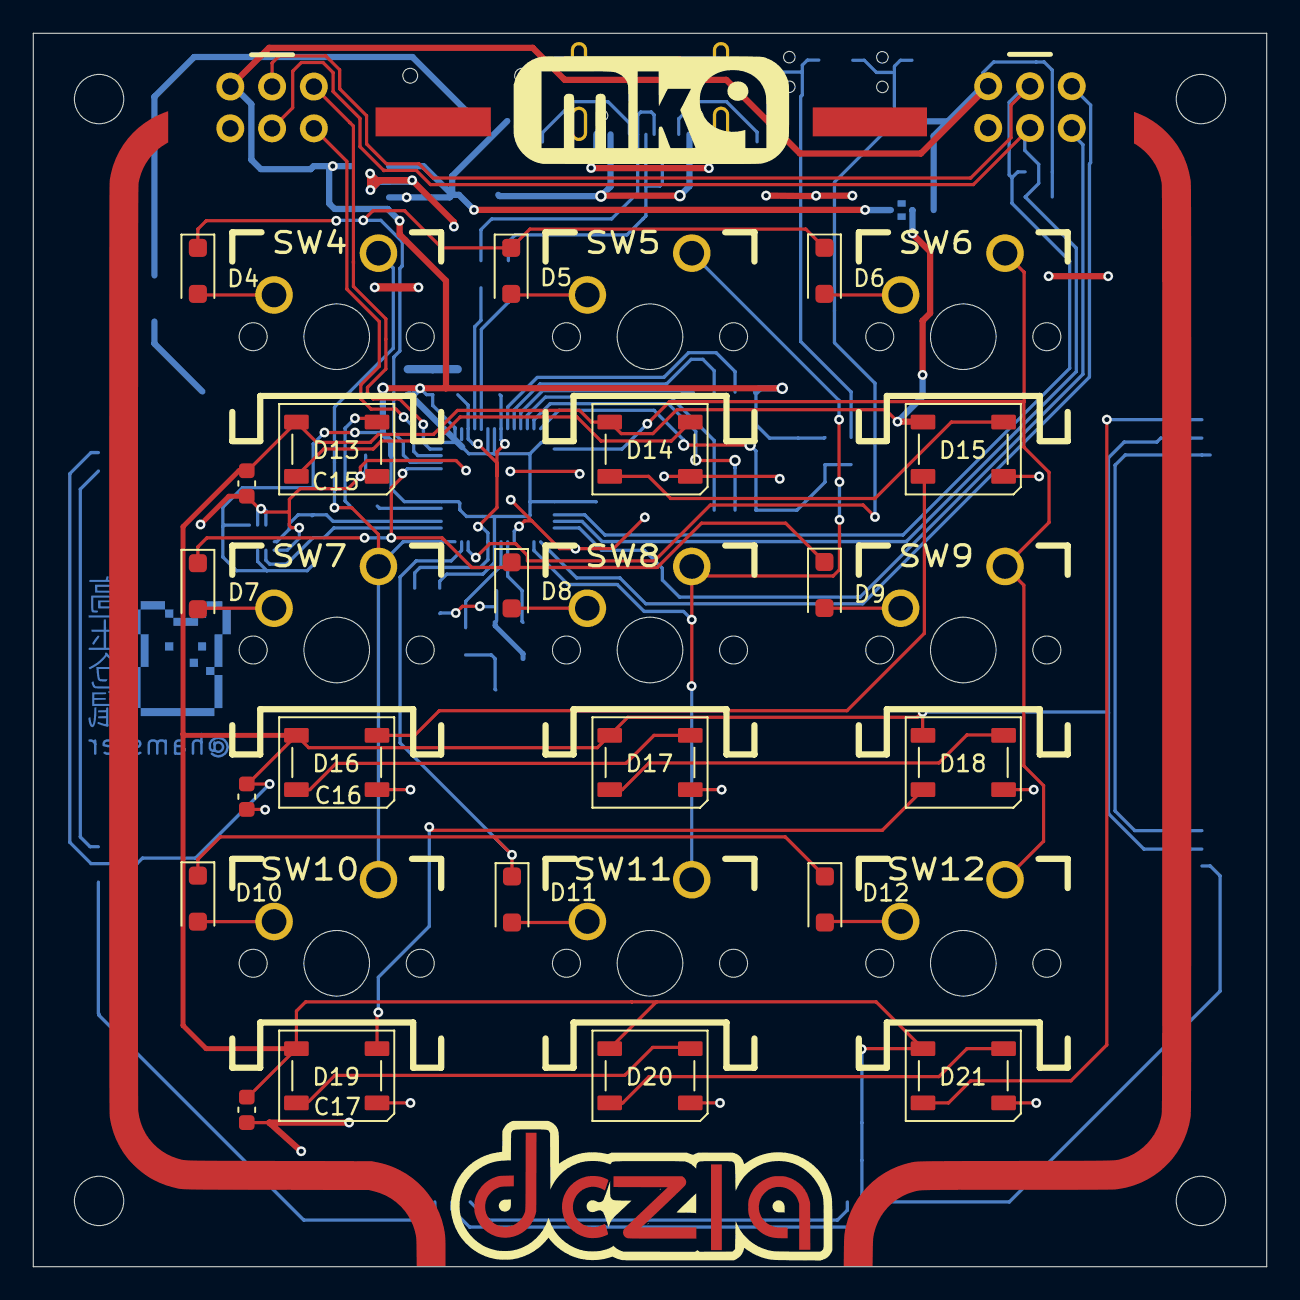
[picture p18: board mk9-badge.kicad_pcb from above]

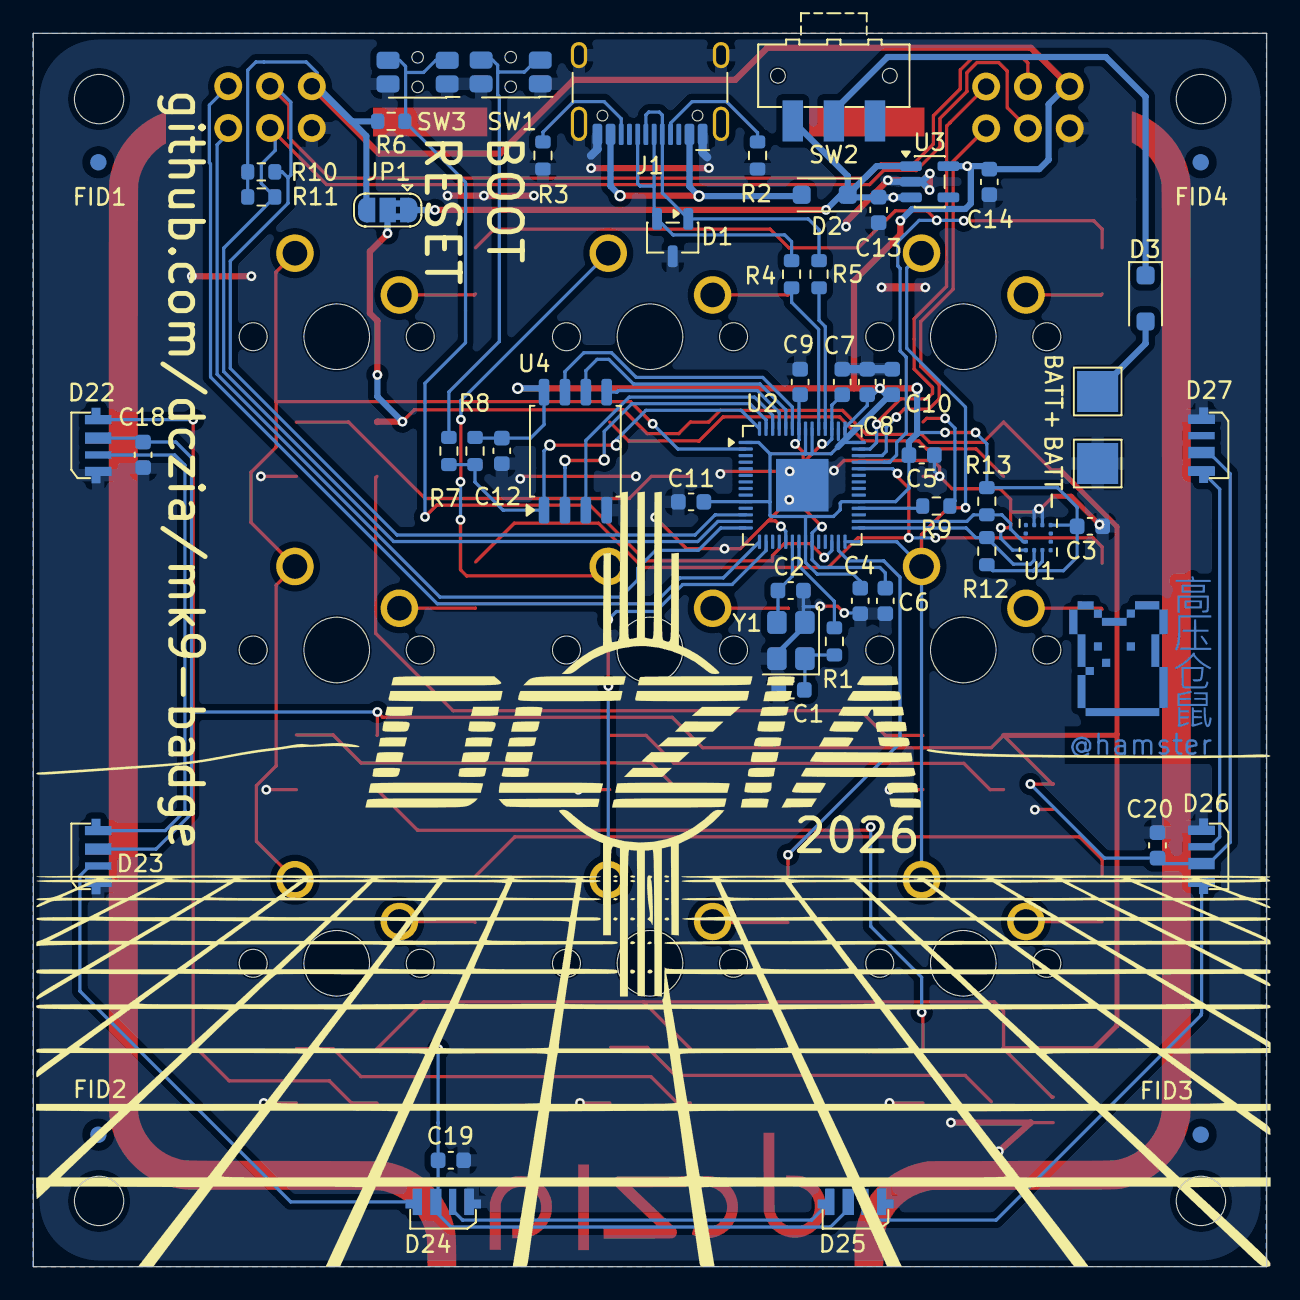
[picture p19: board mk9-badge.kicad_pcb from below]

Board: 2 copper layers, 75.0 x 75.0 mm, 87 parts (55 on the bottom side), 64 nets.

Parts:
C1, C2: 15pF; C_0603_1608Metric
C3, C5, C6, C8, C9, C10, C11, C12, C15, C16, C17, C18, C19, C20: 0.1uF; C_0603_1608Metric
C4, C7, C13, C14: 1uF; C_0603_1608Metric
D1: SP0503BAHT; SOT-23-3
D2, D3, D4, D5, D6, D7, D8, D9, D10, D11, D12: D_Schottky; D_SOD-123F
D13, D14, D15, D16, D17, D18, D19, D20, D21: WS2812B; LED_WS2812B_PLCC4_5.0x5.0mm_P3.2mm_Update
D22, D23, D24, D25, D26, D27: SK6812; LED_SK6812_4020
FID1, FID2, FID3, FID4: Fiducial; Fiducial_1mm_Mask2mm
J1: USB-C; USB_C_Receptacle_HCTL_HC-TYPE-C-16P-01A
JP1: LED Power Select; SolderJumper-3_P1.3mm_Bridged2Bar12_RoundedPad1.0x1.5mm
R1, R7: 1k; R_0603_1608Metric
R2, R3: 5.1k; R_0603_1608Metric
R4, R5: 27R; R_0603_1608Metric
R6, R8: 10k; R_0603_1608Metric
R9: 10R; R_0603_1608Metric
R10, R11, R12, R13: 4.7k; R_0603_1608Metric
SW1: Boot Select; SW_SPST_EVQP7C
SW2: SW_SPDT; SW_SPDT_CK-JS102011SAQN
SW3: Reset; SW_SPST_EVQP7C
SW4, SW5, SW6, SW7, SW8, SW9, SW10, SW11, SW12: SW_Push; CHERRY_SMDLED_100H
TP5: BATT+; TestPoint_Pad_2.5x2.5mm
TP6: BATT-; TestPoint_Pad_2.5x2.5mm
U1: GSDA213; Kionix_LGA-12_2x2mm_P0.5mm_LayoutBorder2x4y
U2: RP2040; QFN-56-1EP_7x7mm_P0.4mm_EP3.2x3.2mm
U3: NCP115ASN330T2G; SOT-23-5
U4: W25Q128JVSIM; SOIC-8_5.3x5.3mm_P1.27mm
X1, X2: Badgelife_sao_connector_v169bis; Badgelife-Shitty-v1.69bis
Y1: ABM8-272-T3; Crystal_SMD_Abracon_ABM8G-4Pin_3.2x2.5mm

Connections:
+3.3V: C3.2, C4.2, C5.2, C8.2, C10.2, C11.2, C12.2, C14.2, JP1.3 (B), R6.2, R8.2, R10.2, R11.2, R12.2, R13.2, U1.3 (VDD_IO), U1.7 (VDD), U2.1 (IOVDD), U2.10 (IOVDD), U2.22 (IOVDD), U2.33 (IOVDD), U2.42 (IOVDD), U2.43 (ADC_AVDD), U2.44 (VREG_IN), U2.48 (USB_VDD), U2.49 (IOVDD), U3.5 (OUT), U4.8 (VCC), X1.1 (VCC), X2.1 (VCC)
C0: SW4.1, SW7.1, SW10.1, U2.28 (GPIO17)
C1: SW5.1, SW8.1, SW11.1, U2.16 (GPIO13)
C2: SW6.1, SW9.1, SW12.1, U2.2 (GPIO0)
CLK: U2.52 (QSPI_SCLK), U4.6 (CLK)
DS0: U2.53 (QSPI_SD0), U4.5 (DI(IO0))
DS1: U2.55 (QSPI_SD1), U4.2 (DO(IO1))
DS2: U2.54 (QSPI_SD2), U4.3 (IO2)
DS3: U2.51 (QSPI_SD3), U4.7 (IO3)
GND: C1.1, C2.1, C3.1, C4.1, C5.1, C6.1, C7.1, C8.1, C9.1, C10.1, C11.1, C12.1, C13.1, C14.1, C15.2, C16.2, C17.2, C18.2, C19.2, C20.2, D1.3 (A), D13.3 (VSS), D14.3 (VSS), D15.3 (VSS), D16.3 (VSS), D17.3 (VSS), D18.3 (VSS), D19.3 (VSS), D20.3 (VSS), D21.3 (VSS), D22.4 (VSS), D23.4 (VSS), D24.4 (VSS), D25.4 (VSS), D26.4 (VSS), D27.4 (VSS), J1.A1 (GND), J1.A12 (GND), J1.B1 (GND), J1.B12 (GND), J1.SH (SHIELD), R2.2, R3.2, SW1.1, SW3.1, TP6.1 (1_1), U1.1 (SA0), U1.8 (GND_IO), U1.9 (GND), U2.19 (TESTEN), U2.57 (GND), U3.2 (GND), U4.4 (GND), X1.2 (GND), X2.2 (GND), Y1.2, Y1.4
unnamed: C1.2, R1.1, Y1.1
unnamed: D1.1 (K), J1.A7 (D-), J1.B7 (D-), R4.2
unnamed: D1.2 (K), J1.A6 (D+), J1.B6 (D+), R5.1
unnamed: D3.2 (A), TP5.1 (1_1)
unnamed: D3.1 (K), SW2.2 (B)
unnamed: D4.2 (A), SW4.2
unnamed: D5.2 (A), SW5.2
unnamed: D6.2 (A), SW6.2
unnamed: D7.2 (A), SW7.2
unnamed: D8.2 (A), SW8.2
unnamed: D9.2 (A), SW9.2
unnamed: D10.2 (A), SW10.2
unnamed: D11.2 (A), SW11.2
unnamed: D12.2 (A), SW12.2
unnamed: D13.4 (DIN), R9.1
unnamed: D13.2 (DOUT), D14.4 (DIN)
unnamed: D14.2 (DOUT), D15.4 (DIN)
unnamed: D15.2 (DOUT), D16.4 (DIN)
unnamed: D16.2 (DOUT), D17.4 (DIN)
unnamed: D17.2 (DOUT), D18.4 (DIN)
unnamed: D18.2 (DOUT), D19.4 (DIN)
unnamed: D19.2 (DOUT), D20.4 (DIN)
unnamed: D20.2 (DOUT), D21.4 (DIN)
unnamed: D22.3 (DOUT), D23.1 (DIN)
unnamed: D23.3 (DOUT), D24.1 (DIN)
unnamed: D24.3 (DOUT), D25.1 (DIN)
unnamed: D25.3 (DOUT), D26.1 (DIN)
unnamed: D26.3 (DOUT), D27.1 (DIN)
unnamed: J1.A5 (CC1), R2.1
unnamed: J1.B5 (CC2), R3.1
unnamed: R7.1, SW1.2
unnamed: R6.1, SW3.2, U2.26 (RUN)
unnamed: C6.2, C7.2, C9.2, U2.23 (DVDD), U2.45 (VREG_VOUT), U2.50 (DVDD)
R0: D4.1 (K), D5.1 (K), D6.1 (K), U2.39 (GPIO27_ADC1)
R1: D7.1 (K), D8.1 (K), D9.1 (K), U2.38 (GPIO26_ADC0)
R2: D10.1 (K), D11.1 (K), D12.1 (K), U2.27 (GPIO16)
RGB: R9.2, U2.32 (GPIO21)
SAO1_1: U2.41 (GPIO29_ADC3), X1.5 (GPIO1)
SAO1_2: U2.40 (GPIO28_ADC2), X1.6 (GPIO2)
SAO2_1: U2.15 (GPIO12), X2.5 (GPIO1)
SAO2_2: U2.14 (GPIO11), X2.6 (GPIO2)
SCL0: R11.1, U2.13 (GPIO10), X1.4 (SCL), X2.4 (SCL)
SCL1: R13.1, U1.12 (SCL), U2.30 (GPIO19)
SDA0: R10.1, U2.12 (GPIO9), X1.3 (SDA), X2.3 (SDA)
SDA1: R12.1, U1.2 (SDA), U2.29 (GPIO18)
SIDE_LEDS: D21.2 (DOUT), D22.1 (DIN)
SS: R7.2, R8.1, U2.56 (QSPI_SS), U4.1 (~CS)
USB_N: R4.1, U2.46 (USB_DM)
USB_P: R5.2, U2.47 (USB_DP)
VBUS: D2.2 (A), J1.A4 (VBUS), J1.A9 (VBUS), J1.B4 (VBUS), J1.B9 (VBUS)
VCC: C13.2, D2.1 (K), JP1.1 (A), SW2.3 (C), U3.1 (IN), U3.3 (EN)
VLED: C15.1, C16.1, C17.1, C18.1, C19.1, C20.1, D13.1 (VDD), D14.1 (VDD), D15.1 (VDD), D16.1 (VDD), D17.1 (VDD), D18.1 (VDD), D19.1 (VDD), D20.1 (VDD), D21.1 (VDD), D22.2 (VDD), D23.2 (VDD), D24.2 (VDD), D25.2 (VDD), D26.2 (VDD), D27.2 (VDD), JP1.2 (C)
XTAL_IN: C2.2, U2.20 (XIN), Y1.3
XTAL_OUT: R1.2, U2.21 (XOUT)

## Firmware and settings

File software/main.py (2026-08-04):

"""MicroPython entry point for the DCZia MK9 badge."""

from badge import Badge
from config import THEME_NAMES
from hardware import Hardware
from serial_menu import make_default_stream
import usb_keyboard
import user_config

hardware = Hardware()
badge = Badge(hardware, make_default_stream())

saved_config = user_config.load()
if saved_config:
    brightness = saved_config.get("brightness")
    if isinstance(brightness, (int, float)):
        hardware.set_brightness(brightness)
    theme = saved_config.get("theme")
    if isinstance(theme, int) and 0 <= theme < len(THEME_NAMES):
        badge.theme = theme
    party_bpm = saved_config.get("party_bpm")
    if isinstance(party_bpm, (int, float)) and party_bpm > 0:
        badge.party_bpm = party_bpm

print("MK9 MicroPython firmware")
print("accelerometer:", "ready" if hardware.accelerometer else "not detected")
if hardware.accelerometer_error:
    print("accelerometer detail:", hardware.accelerometer_error)
print("USB keyboard:", "configured" if usb_keyboard.error() is None else "unavailable")
print("SAO bus:", "ready" if hardware.sao_i2c else "unavailable")
print("User config:", "loaded" if saved_config else "defaults")
print("Serial console: type 'help' then Enter for commands")

badge.run()

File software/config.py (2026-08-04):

"""Hardware map and user-tunable settings for the MK9 badge."""

# As-built RP2040 wiring.
PIXEL_PIN = 21
NUM_PIXELS = 15
NUM_KEY_LEDS = 9
BACKLIGHT_START = 9

ROW_PINS = (27, 26, 16)
COLUMN_PINS = (17, 13, 0)

ACCEL_I2C_ID = 1
ACCEL_SDA_PIN = 18
ACCEL_SCL_PIN = 19

# The SAO pins are not a valid hardware-I2C pair on RP2040, so hardware.py
# intentionally creates a SoftI2C bus for them.
SAO_SDA_PIN = 9
SAO_SCL_PIN = 10
SAO_GPIO_PINS = (29, 28, 12, 11)

# Animation/input tuning.
GLOBAL_BRIGHTNESS = 0.30
FRAME_MS = 25
KEY_SCAN_MS = 3
DEBOUNCE_SCANS = 3
LONG_PRESS_MS = 750
STARTUP_MS = 3200
PARTY_BPM = 175.0
PARTY_BPM_MIN = 1.0
PARTY_BPM_MAX = 999.0
PARTY_BPM_STEP = 2.0

# While Party Mode is active, these two keys (0-based indices; Key 7/Key 8 in
# the physical 1-9 numbering -- the ones that normally type "1" and "2") stop
# sending USB numpad taps and instead nudge the tempo down/up by
# PARTY_BPM_STEP per short press. A long press on either still selects that
# key's own theme as usual.
PARTY_BPM_DOWN_KEY = 6
PARTY_BPM_UP_KEY = 7

# Key 9 (0-based index 8, normally types "3") is a tap-tempo input while
# Party Mode is active: tap it in time with music and the average interval
# between taps becomes the new BPM. A gap longer than PARTY_TAP_TIMEOUT_MS
# since the last tap starts a fresh sequence instead of averaging with stale
# taps; PARTY_TAP_HISTORY caps how many recent taps are averaged together.
PARTY_TAP_TEMPO_KEY = 8
PARTY_TAP_TIMEOUT_MS = 2000
PARTY_TAP_HISTORY = 5

# key number -> USB keypad key code (7 8 9 / 4 5 6 / 1 2 3)
NUMPAD_CODES = (95, 96, 97, 92, 93, 94, 89, 90, 91)

THEME_NAMES = (
    "Party Mode",
    "Vaporwave",
    "Deep Ocean",
    "Ember",
    "Matrix",
    "Ultraviolet",
    "Sunset",
    "Glacier",
    "Moonlight",
    "Prism",
)

PARTY_MODE_THEME = THEME_NAMES.index("Party Mode")

# Boot-time default theme (before any saved user_config.json is applied).
# Named explicitly rather than hardcoded as 0, since Party Mode -- not a calm
# ambient theme -- now lives at index 0.
DEFAULT_THEME = THEME_NAMES.index("Prism")

# (row, column), including the six perimeter LEDs.
LED_POSITIONS = (
    (0.0, 0.0),
    (0.0, 1.0),
    (0.0, 2.0),
    (1.0, 0.0),
    (1.0, 1.0),
    (1.0, 2.0),
    (2.0, 0.0),
    (2.0, 1.0),
    (2.0, 2.0),
    (-0.7, 2.7),
    (1.0, 3.2),
    (2.7, 2.7),
    (2.7, -0.7),
    (1.0, -1.2),
    (-0.7, -0.7),
)

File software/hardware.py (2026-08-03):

"""Initialise MK9 peripherals using MicroPython's machine APIs."""

from machine import I2C, Pin, SoftI2C
import neopixel

from config import (
    ACCEL_I2C_ID,
    ACCEL_SCL_PIN,
    ACCEL_SDA_PIN,
    GLOBAL_BRIGHTNESS,
    NUM_PIXELS,
    PIXEL_PIN,
    SAO_GPIO_PINS,
    SAO_SCL_PIN,
    SAO_SDA_PIN,
)
from key_matrix import KeyMatrix
from msa301 import MSA301

def _brightness_lut(level):
    return bytes([int(value * level) for value in range(256)])


class Hardware:
    def __init__(self):
        self.pixels = neopixel.NeoPixel(Pin(PIXEL_PIN, Pin.OUT), NUM_PIXELS)
        self.keys = KeyMatrix()
        self.frame = [(0, 0, 0)] * NUM_PIXELS
        self.brightness = GLOBAL_BRIGHTNESS
        self._lut = _brightness_lut(self.brightness)

        self.accel_i2c = None
        self.accelerometer = None
        self.accelerometer_error = None
        try:
            self.accel_i2c = I2C(
                ACCEL_I2C_ID,
                sda=Pin(ACCEL_SDA_PIN),
                scl=Pin(ACCEL_SCL_PIN),
                freq=400000,
            )
            self.accelerometer = MSA301(self.accel_i2c)
        except Exception as error:
            self.accelerometer_error = error

        # Preserve both SAO connectors. SoftI2C is required for this PCB's
        # GP9/GP10 routing because it is not one RP2040 hardware-I2C pin pair.
        self.sao_i2c = None
        self.sao_gpio = ()
        self.sao_error = None
        try:
            self.sao_i2c = SoftI2C(
                sda=Pin(SAO_SDA_PIN),
                scl=Pin(SAO_SCL_PIN),
                freq=100000,
            )
            self.sao_gpio = tuple(Pin(pin, Pin.IN, Pin.PULL_UP) for pin in SAO_GPIO_PINS)
        except Exception as error:
            self.sao_error = error

    def set_brightness(self, level):
        self.brightness = max(0.0, min(1.0, level))
        self._lut = _brightness_lut(self.brightness)

    def show(self, frame=None):
        if frame is None:
            frame = self.frame
        # NeoPixel stores three-channel pixels in GRB byte order. Filling the
        # buffer directly avoids 15 tuple allocations and method calls per
        # frame; the lookup also replaces repeated floating-point scaling.
        buffer = self.pixels.buf
        lut = self._lut
        offset = 0
        for color in frame:
            buffer[offset] = lut[color[1]]
            buffer[offset + 1] = lut[color[0]]
            buffer[offset + 2] = lut[color[2]]
            offset += 3
        self.pixels.write()

    def off(self):
        self.pixels.fill((0, 0, 0))
        self.pixels.write()

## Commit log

2026-06-26 Porting in Zippy badge firmware Adding in testing firmware Adding a README
    [mk9-badge-NPTH.drl, mk9-badge-PTH.drl]
2026-07-09 Updated artwork Added as-built rev 1 PCB
    [BOM.xlsx, G_PRO_3.0_Switch_KS-9E10B055NN-Y51_1.STEP, G_PRO_3.0_Switch_KS-9E10B055NN-Y51_2.STEP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]
2026-07-21 Rebuild badge lighting and fix hardware pin
    [color_tools.py, test_color_tools.py]
2026-07-21 Fix key matrix diode direction
2026-07-23 Flow light intensity with badge movement
2026-08-03 Add a typed serial console for live badge control
    Lets you type commands (help/status/theme/brightness/accel/reset/bootloader)
    over the badge's existing USB-CDC connection while it's running, instead of
    only being able to Ctrl-C into the REPL. Brightness becomes runtime-mutable
    in hardware.py to support the new command. Verified on real hardware, which
    also caught a CRLF double-dispatch bug the host-only tests missed.
    [badge.py, hardware.py, main.py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]
2026-08-03 Persist theme and brightness across reboots
    Saves the active theme and brightness to /user_config.json on flash
    whenever either changes (long-press, or the theme/brightness serial
    commands), and restores them on boot so the badge remembers your
    settings instead of always starting from config.py's defaults.
    [badge.py, main.py, serial_menu.py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]
2026-08-04 Drop the key-press printout from the hardware test script
    Keeps the diagnostic console output focused on accelerometer readings;
    the white LED feedback already shows which key is held.
2026-08-04 Add text-adventure game mode and a Party Mode LED theme
    Text adventure: typing `play` at the serial console starts a small
    room-based game (rooms.py/game.py) that takes over the console until
    `quit`, using the 9 key LEDs as a red/yellow/green status board. Content
    (rooms, items, puzzles) lives entirely in rooms.py so it's easy to build
    out without touching the engine. Supports look/go/take/use/hint/save/
    load/restart, and auto-saves progress on quit.
    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
2026-08-04 Add Party Mode tap-tempo (key 9) and revert to every-beat pulsing
    Key 9 is now a tap-tempo input while Party Mode is active: tap it in
    time with music and the average interval across the last few taps
    becomes the new BPM. A gap over 2 seconds since the last tap starts a
    fresh tapping sequence instead of averaging with stale ones. Same
    suppress-HID/keep-long-press behavior as the existing key 7/8 tempo
    controls.
    Also removes the beat divisor added earlier, so Party Mode's pattern
    changes on every beat again instead of every other one.
    [badge.py, config.py, test_badge_behavior.py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]
